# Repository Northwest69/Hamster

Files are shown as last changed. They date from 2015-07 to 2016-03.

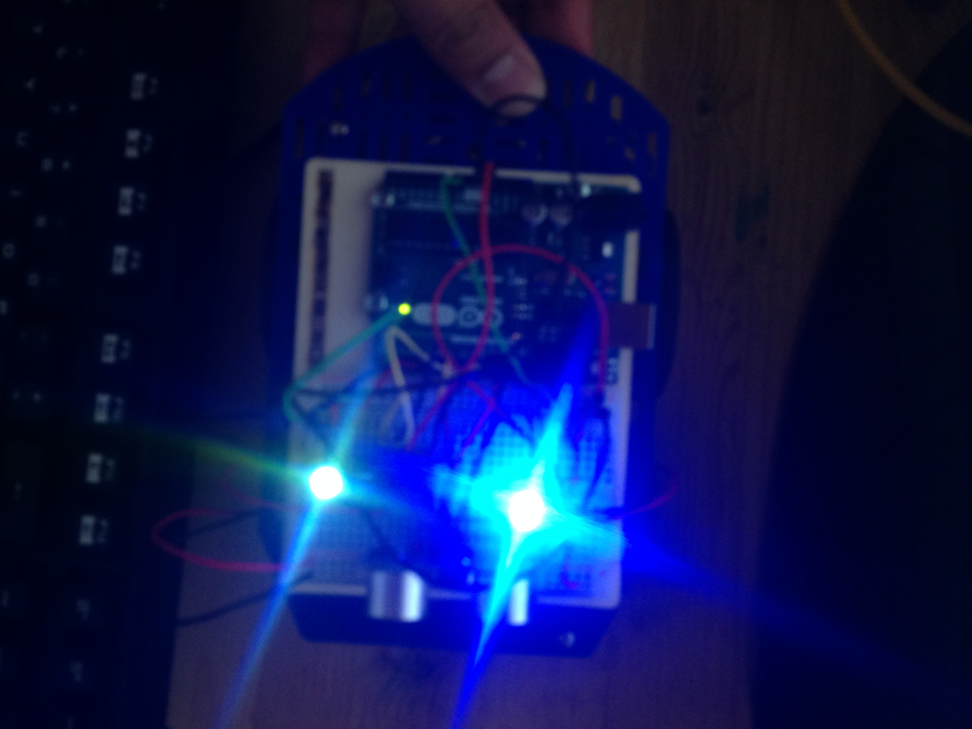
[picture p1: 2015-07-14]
Pictures/Hamster 0.2.0-1.JPG

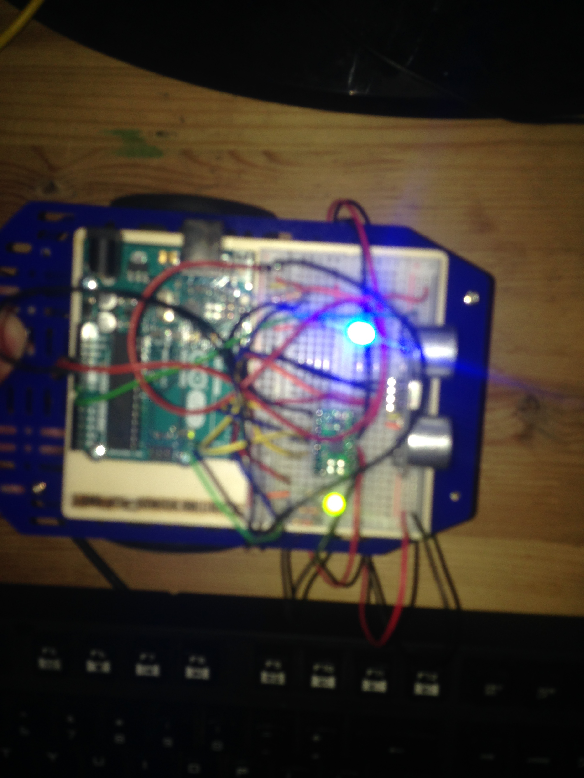
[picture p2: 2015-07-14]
Pictures/Hamster 0.2.0-2.JPG

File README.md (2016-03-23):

Hamster
=======
Firmware: 1.3.123 
Created by Peter Chau
Start Date: June 5, 2015

Hamster checks if ultraSensor sees anything in front of it. If it does, it chooses an random action based on a set of probabilities. Otherwise, Hamster drives forward. 

When Hamster is in 'Learning Mode', it evaluates it's actions and modifies the probability set until it's tried a set amount of times. The blue light is on when it's in 'Learning Mode'!

When Hamster is in 'Roam Mode', it uses the probability set to avoid objects!

When Hamster is in 'Standby Mode', it does nothing until it sees something. When it does see something, it enters 'Roam Mode'

Data is sent to Windows or Linux machine via bluetooth serial terminal.

Hardware: Arduino Uno, TI DRV8833 Dual H-Bridge Motor Driver, HC-SR04 Ultra01 + Ultrasonic Range Finder, Blue tooth Shield HC-06, HMC5883L triple axis compass
   
Log:
----
###8/14/2015 1.6.0 / 1.0.0
	Added more decimals to display probabilities
	Added new color palette

###8/13/2015 1.5.0 / 0.7.0
	Update reset command from processing to Arduino
		All fields always match Arduino
	Changed Textfield labels
	Arduino can now reset to initial probabilities, have probabilities set from processing
	Arduino can now send probabilities to processing
	Add probability stream to computer display  
	Read/Write probabilities to text file

###8/12/2015 1.4.0 / 0.5.0
	Started Implementing ControlP5 for GUI
	Processing can now set duty cycle, rotate degree, max learning attempts, and reset learning attempts
		Added submit button and key (enter)
	Learning attempts field added and Auto update display of learning attempts on processing

###8/11/2015 1.3.123 / 0.2.123
	Arduino can handle set_speed, Max learning attempts, reset learning attempts, and rotate degrees
	Processing keyPressed check added. Now processing stops serial writing when key released. 
		Hamster reenters normal operations when no signal received.

###8/10/2015 1.2.0
	Now using SerialCommand Library for string and argument based serial communication
		"D 0\r" = Drive forwards
	Fixed Standby and Roam modes

###8/9/2015 1.1.1
	Created Processing software for Hamster
	Allow Arduino to Receive Commands via bluetooth
		Can control driving instructions for drive train
			via on screen buttons
			via keys (up down left right control (stop))
	Configured Bluetooth to communicate at 38400 BAUD
		Optimized timing  to 1 loop per 50ms

###8/9/2015 1.0.1
	Memory optimizations
		Use Flash memory for strings
			Read from strings from memory for better performance (save the string only 1 time);
		Reduced code appearances for printing current probabilities more than once
		Use bytes, and boolean data types when possible

###8/8/2015 1.0.0
   Add mode switch (Learning, Standby, Roam)
   		Implemented all 3 modes
   		
###8/6/2015
	Created a prototype shield
	Power LED
	On/Off Switch

###8/4/2015 0.3.4
   Cleaned up and optimized code

###7/30/2015 0.3.3
   Implemented rotate to a degree compass navigation
      Hard-coded degrees to drive train
	  It rotates a fixed amount then stops when it's clear
   Stop motors when we see something	

###7/29/2015 0.3.2
   Enable triple axis compass
   Implemented compass navigation to drive straight
	   Added buffer so no adjustment occurs when heading difference is less than 1 degree 

###7/27/2015
   Added a probability floor

###7/22/2015
   Changed name of bluetooth module to: Hamster
   Changed Password to: Swag
   Developed Bluetooth Config Sketch

###7/21/2015
   Add Bluetooth functionality via HC-06 Bluetooth Shield
	  Sends data to computer
	  Formatted Serial data
   Changed Colors for better aesthetic
   Implement software serial for bluetooth

###7/15/2015
   Added Debounce 2 library to add functionality to debounce buttons. Perhaps this can be used to buffer actions
   Test Hamster at learningAttempts = 100, increased to 500. This works very well.
   Add exit AAN if a probability threshold is reached

###7/13/2015
   The issue was the USB cable. It is now fixed!
   Changed neural network adjustments to small decreases and increases (from 100% to 1%, and 33% to 0.33%)
   Add max training attempts (50)
     Add exit if n training attempts reached
   Add EEPROM library
     Update probabilities to EEPROM
     Nevermind... blew max writes on mem 0 already. Fuck that. Will wait for bluetooth communications
   Now using 5 different actions (stop, forwards, backwards, rotate right, rotate left)
   Add active Feedforward Back Propagation Neural Network
     Add "training mode"
   Add LED to indication which mode Hamster is in

###7/12/2015
   Added a Feedforward Neural Network for obstacle avoidance
   USB drive on computer mangled again.... Have thought out robot more. Very happy with current results.

###7/10/2015
   Ultrasonic range finder working well, however there is lag between when it detects an object and when it takes action.
     Calibrated Sensor
   Poor wheel alignment
   Implemented a status LED

###7/9/2015
   Create DC Motor drive function. void driveTrain(int instruction, int dutyCycle, int period)
   Implemented driveTrain()
   Created better serial messages
   Reworked ultrasonic range finder pinging as a state function
   ultrasonic range find needs to be calibrated. wtf. it's slow.
   ok now the robot works but is really dumb lol. it runs into stuff... lag time... momentum... go and :speed up ping

###7/8/2015
   Arduino Uno now functioning - Window's driver needed to be installed. Gave it a fresh battery charge as well.
   Updated Breadboard and schematic - was missing Uno VIN.

###7/7/2015
   Created Breadboard Diagram
   Created Schematic

###7/6/2015
   Installed DVR8833 library
   Mapped dutyCycle to motorSpeed
   I seem to have fired my Arduino UNO. Computer won't recognize it however when plugged into the wall via USB, the board works fine.

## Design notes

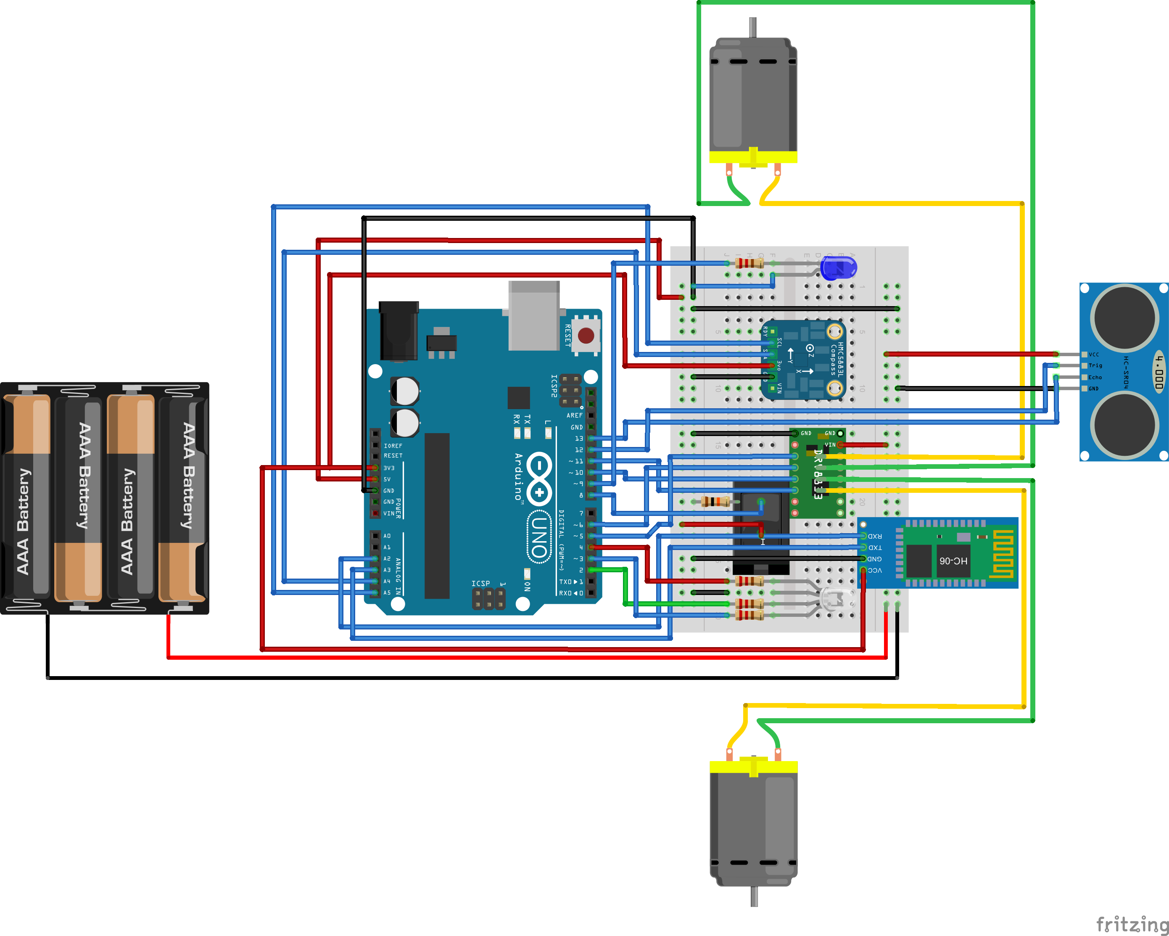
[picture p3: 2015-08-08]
Schematic/Bread Board - Hamster.png

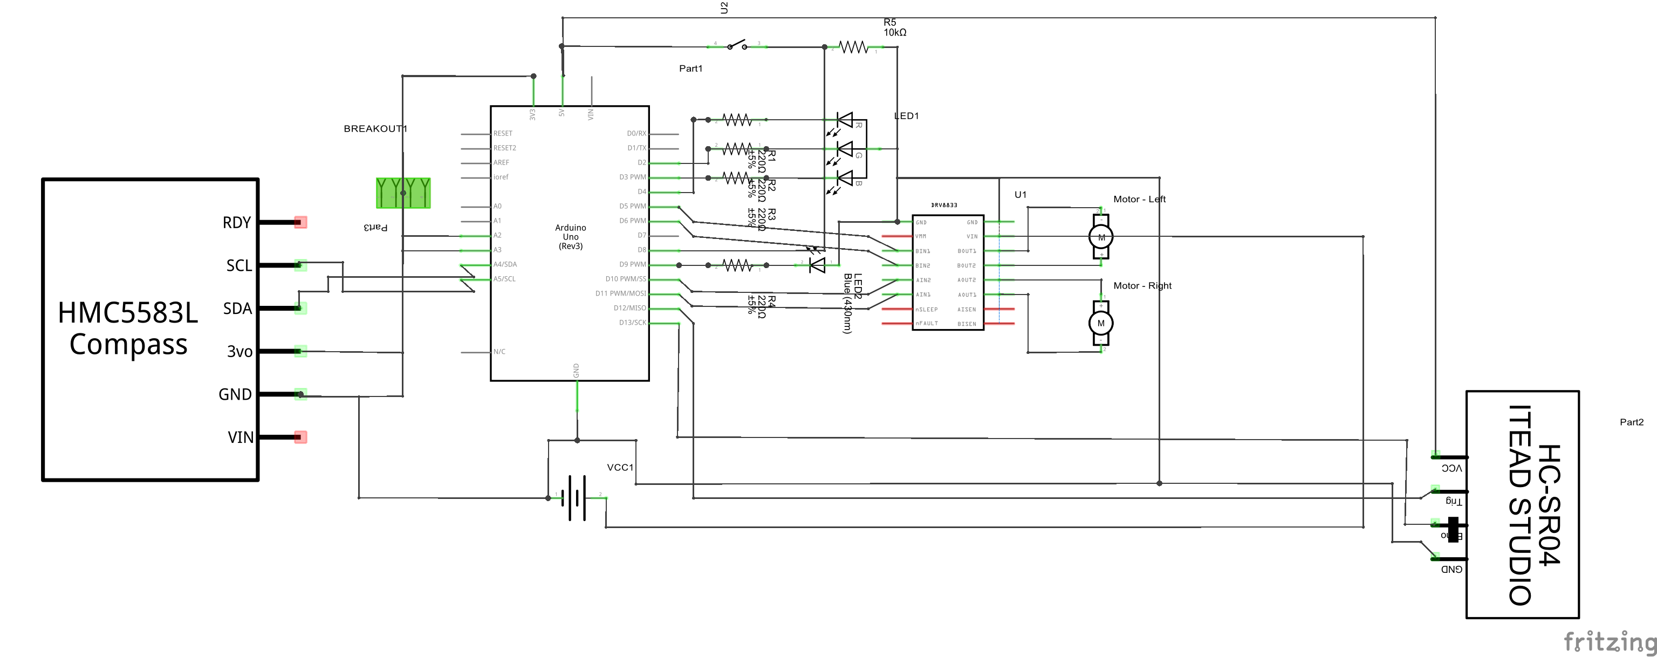
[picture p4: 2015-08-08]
Schematic/Schematic - Hamster.png

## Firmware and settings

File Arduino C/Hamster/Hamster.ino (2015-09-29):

/* Hamster
   Firmware: 1.6.0
   Created by Peter Chau
   Start Date: June 5, 2015
   Hardware: Arduino Uno, TI DRV8833 Dual H-Bridge Motor Driver, HC-SR04 Ultra01 + Ultrasonic Range Finder, Bluetooth Shield HC-06, and HMC5883L Triple axis compass
*/

#include <SoftwareSerial.h> // Include Software Serial to allow programming and bluetooth at the same time
#include <NewPing.h> // Include NewPing to handle ultraSensor data
#include <DRV8833.h> // Include DRV8833 Dual Motor Driver Carrier - Pololu  
#include <Wire.h>
#include <Adafruit_Sensor.h>
#include <Adafruit_HMC5883_U.h>
#include <math.h>
#include <SerialCommand.h> // Include to parse serial in strings

/* Bluetooth Communications constants */
const byte rxPin = A2;
const byte txPin = A3;

/* Compass Navigations variables */
float currentHeading;
float rotateDegree = 30;
byte val; // For receiving commands from Processing

/* Status LED constants and variables */
const byte statusLEDPins[] = {4, 2, 3}; // Array for Status LED with pins for red, green, and blue
byte status;

/* Drive Train constant and variables */
const byte rightMotor1 = 11;   // PWM control Right Motor -
const byte rightMotor2 = 10;   // PWM control Right Motor +
const byte leftMotor1 = 5;  // PWM control Left Motor +
const byte leftMotor2 = 6;  // PWM control Left Motor -
const int loopSpeed = 50; // 50ms between loops
long loopTimer = 0; // will store last time loop occurred
byte driveInstruction;
byte dutyCycle = 75; // Set initial 0% duty cycle PWM

/* Learning and Roam Mode constants and variables */
const byte modeSwitch = 8; // Momentary switch for putting Hamster in learn mode
const byte modeLED = 9; // LED to indicate what mode we are in
const byte roamPin = 7; // Momentary switch for putting Hamster in learn mode
boolean modeRoam = LOW; // Set inital state to drive mode (learn mode off)
boolean modeState = LOW; // Set inital state to drive mode (learn mode off)

/* Neural Network constants and variables */
const float probabilityThreshold = 0.75; // Set max probability threshold to 75%
const float probabilityFloor = 0.01; // Set probability error to 1%
boolean probabilityCheck = false; // Counter for checking if probabilities high threshold
int maxAttempts = 500; // Set max attempts to learn
int learningAttempts = 0; // Set initial attempts to learn
float probability[] = {0.16667, 0.16667, 0.16667, 0.16667, 0.16667, 0.16667}; // Set equal initial probabilities
float probabilityRemainder; // To hold remaining probability when floor has been reached, then split up amoung other probabilities

/* Ultrasonic Rangefinder constants and variables */
const byte ultraSensorTriggerPin = 12;  // Arduino pin tied to trigger pin on the ultrasonic sensor.
const byte ultraSensorEchoPin = 13;  // Arduino pin tied to echo pin on the ultrasonic sensor.
const int maxDistance = 100;
const int safeZone = 40; // 40cm between Hamster and any object
int ultraSensorCM[1]; // will stored distance from object in cm
unsigned int ultraSensorRaw; // will store raw ultrasensor range finder distance

DRV8833 driver = DRV8833(); // Create an instance of the DRV8833:
NewPing ultraSensor(ultraSensorTriggerPin, ultraSensorEchoPin, maxDistance); // NewPing setup of pins and maximum distance.
SoftwareSerial bluetooth = SoftwareSerial(rxPin, txPin); // RX, TX for bluetooth
SerialCommand SCmd(bluetooth);   // The demo SerialCommand object, using the SoftwareSerial Constructor

Adafruit_HMC5883_Unified compass = Adafruit_HMC5883_Unified(12345); // Create compass object

void setup() {
  /* Initalize pins for bluetooth*/
  pinMode(rxPin, INPUT);
  pinMode(txPin, OUTPUT);
  bluetooth.begin(38400);

  /* Setup callbacks for SerialCommand commands */
  SCmd.addCommand("D", driveCommand); // Drive command
  SCmd.addCommand("S", setDutyCycle); // Speed command
  SCmd.addCommand("L", learningMax); // Max Learning Attempts command
  SCmd.addCommand("R", reset); // Reset Learning Attempts command
  SCmd.addCommand("T", setRotateDegree); //Set Rotate Degree command
  SCmd.addCommand("P", setProbability); //Set Rotate Degree command
  
  /* Initialize mode button and LED */
  pinMode(modeSwitch, INPUT);
  pinMode(modeLED, OUTPUT);

  /* Initialise the sensor */
  if (!compass.begin()) {
    while (1);
  }

  /* Attach the motors to the input pins: */
  driver.attachMotorA(rightMotor1, rightMotor2);
  driver.attachMotorB(leftMotor1, leftMotor2);

  /* Attach status LED to output pins */
  for (byte x = 0; x < 3; x++) {
    pinMode(statusLEDPins[x], OUTPUT);
  }

  bluetooth.println("\n\rH A M S T E R v1.3.0 <3\n");
  statusLed(0); // Set status LED to Ready (green)
}

void loop() {
  if (bluetooth.available()>0){
    SCmd.readSerial();     // Process serial commands
  }
  
  /* Measure the time since last loop */
  unsigned long currentLoopMillis = millis(); // record current time
  if (currentLoopMillis - loopTimer > loopSpeed) { // save the last time you looped
    loopTimer += loopSpeed; // update time since last ping

    statusLed(4); // Ping status (light blue)
    ultraSensorRaw = ultraSensor.ping(); // Send ping, get ping time in microseconds (uS).

    /* Hamster checks if ultraSensor sees anything 40 cm in front of it */
    ultraSensorCM[0] = ultraSensorRaw / US_ROUNDTRIP_CM; // Convert ping time to distance in cm (0 = outside set distance range)
    if (ultraSensorCM[0] > 0 && ultraSensorCM[0] <= safeZone) {
      driveTrain(6, dutyCycle, 0, currentHeading); // Stop motors when something is detected within safe zone
      statusLed(1); // Object Avoidance status (Red)

      /* Use probability to pick an object avoidance action and perform it */
      driveInstruction = weightedRandom(probability);
      driveTrain(driveInstruction, dutyCycle, rotateDegree, currentHeading);

      modeState = digitalRead(modeSwitch); // What mode are we in? Learning or Drive mode.

      /* Use Forewardfeed Back Proprogation Neural Network if Hamster is in Learning Mode and has tried to learn less than max learning attempts */
      if (modeState == HIGH && (learningAttempts < maxAttempts)) {

        /* Check if any probability has reached the probability threshold */
        for (byte x = 0; x < 6; x++) {
          if (probability[x] >= probabilityThreshold) {
            probabilityCheck = true;
            digitalWrite(modeLED, LOW); // Turn off Learning Mode LED
          }
        }

        if (probabilityCheck == false) {
          digitalWrite(modeLED, HIGH); // Turn on Learning Mode LED

          ultraSensorRaw = ultraSensor.ping(); // Ping and save it to ultraSensorCM[1]
          ultraSensorCM[1] = ultraSensorRaw / US_ROUNDTRIP_CM;

          if (ultraSensorCM[1] <= ultraSensorCM[0]) { // Check if action was successful based on change in distance
            for (byte x = 0; x < 6; x++) { // Decrease drive instruction's probability
              if (x == driveInstruction) {
                probability[x] = probability[x] - 0.001000;
              } else {
                probability[x] = probability[x] + 0.000167;
              }
              status = 5; // Action Failed status (light red)
            }
          }
          else {
            for (byte x = 0; x < 6; x++) { // Increase drive instruction's probability
              if (x == driveInstruction) {
                probability[x] = probability[x] + 0.001000;
              } else {
                probability[x] = probability[x] - 0.000167;
              }
              status = 2; // Action Success status (Blue)
            }
          }

          /* Check if any probabilityFloor has been reached*/
          for (byte x = 0; x < 6; x++) {
            if (probability[x] <= probabilityFloor) {
              /* Split remaining probability up between other probabilities */
              probabilityRemainder = probability[x];
              probability[x] = 0;
              for (byte x = 0; x < 6; x++) {
                if (probability != 0) {
                  probability[x] += probabilityRemainder / 6;
                }
              }
            }
          }

          learningAttempts++; // Increase learning tracker
          
          bluetooth.print("C "); bluetooth.println(learningAttempts);
          bluetooth.print("P "); bluetooth.print(String(probability[0], 6));
          bluetooth.print(" "); bluetooth.print(String(probability[1], 6));
          bluetooth.print(" "); bluetooth.print(String(probability[2], 6));
          bluetooth.print(" "); bluetooth.print(String(probability[3], 6));
          bluetooth.print(" "); bluetooth.print(String(probability[4], 6));
          bluetooth.print(" "); bluetooth.println(String(probability[5], 6));
        }
      } else if (modeState == LOW || (learningAttempts >= maxAttempts)) {
        digitalWrite(modeLED, LOW); // Turn off Learning Mode LED
      }

    } else {
      // Go forwards
      driveInstruction = 0; // Drive Forwards
      status = 3; // Wander status (Purple)

      /* Check if we are driving straight */
      if (driveInstruction == 0) { //
        float targetHeading = currentHeading; // Set target heading
        currentHeading = readCompass(); // Find current heading
        float difference = targetHeading - currentHeading;
        if ( difference > -1 && difference < 1) { // Add buffer so this doesn't run all the time
          driveInstruction = adjustHeading(difference); // Determine rotation direction: CCW or CW
        }
      }

      /* Check if we are in Standby Mode */
      modeRoam = digitalRead(roamPin);
      if (modeRoam == HIGH || modeState == HIGH) {
        currentHeading = readCompass(); // Get current heading
        driveTrain(driveInstruction, dutyCycle, rotateDegree, currentHeading);
      }
    }
    statusLed(status);
  }

} // loop() end

void driveCommand() {
  int aNumber;
  char *arg;

  arg = SCmd.next();
  if (arg != NULL)  {
    aNumber = atoi(arg);  // Converts a char string to an integer
    if (aNumber >= 0 && aNumber < 7) {
      currentHeading = readCompass(); // Get current heading
      driveTrain(aNumber, dutyCycle, rotateDegree, currentHeading);
    }
  }
}

void setDutyCycle() {
  int aNumber;
  char *arg;

  arg = SCmd.next();
  if (arg != NULL)  {
    aNumber = atoi(arg);  // Converts a char string to an integer
    if (aNumber >= 0 && aNumber <= 100) {
      dutyCycle = aNumber; // Set duty cycle PWM
    }
  }
}

void setRotateDegree() {
  int aNumber;
  char *arg;

  arg = SCmd.next();
  if (arg != NULL)  {
    aNumber = atoi(arg);  // Converts a char string to an integer
    if (aNumber >= 1 && aNumber <= 360) {
      rotateDegree = aNumber; // Set max attempts to learn
    }
  }
}

void learningMax() {
  int aNumber;
  char *arg;

  arg = SCmd.next();
  if (arg != NULL)  {
    aNumber = atoi(arg);  // Converts a char string to an integer
    if (aNumber >= 0 && aNumber <= 10000) {
      maxAttempts = aNumber; // Set max attempts to learn
    }
  }
}

void setProbability() {
  int aNumber;
  char *arg;

  for(int x = 0; x < 6; x++){
  arg = SCmd.next();
  if (arg != NULL)  {
    aNumber = atoi(arg);  // Converts a char string to an integer
    if (aNumber >= 0 && aNumber <= 1) {
      probability[x] = aNumber; // Set max attempts to learn
    }
  }
}
}

void reset() {
  // Reset to initial values
  learningAttempts = 0;
  maxAttempts = 500;
  dutyCycle = 75;
  rotateDegree = 30;
  for(int x = 0; x < 6; x++){
      probability[x] = 0.1666667; // Set max attempts to learn
    }
  }

/* Drive Train for 2 motors on opposite sides */
void driveTrain(byte instruction, byte dutyCycle, float rotateDegree, float currentHeading) {
  int motorSpeed = map(dutyCycle, 0, 100, 0, 255); // Map motorSpeed (255 - 0) to dutyCycle (0 - 100)
  float targetHeading;
  float difference;

  switch (instruction) {
    case 0: // Forward
      driver.motorAForward(motorSpeed);
      driver.motorBForward(motorSpeed);
      break;
    case 1: // Backwards
      driver.motorAReverse(motorSpeed);
      driver.motorBReverse(motorSpeed);
      break;
    case 2: // Rotate CW
      if ((currentHeading + rotateDegree) >= 360) {
        targetHeading = currentHeading + rotateDegree - 360; // Set target heading
      } else {
        targetHeading = currentHeading + rotateDegree; // Set target heading
      }
      difference = targetHeading - currentHeading;
      while ((difference < -15) || (difference > 15)) { // Add buffer so this doesn't run all the time
        driver.motorAReverse(motorSpeed);
        driver.motorBForward(motorSpeed);
        currentHeading = readCompass(); // Find current heading
        difference = targetHeading - currentHeading;
        if ((difference < 10) && (difference > -10)) {
          break;
        }
      }
      break;
    case 3: // Rotate CCW
      if ((currentHeading - rotateDegree) < 0) {
        targetHeading = currentHeading - rotateDegree + 360; // Set target heading
      } else {
        targetHeading = currentHeading - rotateDegree; // Set target heading
      }
      difference = targetHeading - currentHeading;
      while ( (difference < -15) || (difference > 15)) { // Add buffer so this doesn't run all the time
        driver.motorAForward(motorSpeed);
        driver.motorBReverse(motorSpeed);

        currentHeading = readCompass(); // Find current heading
        difference = targetHeading - currentHeading;
        if ((difference < 10) && (difference > -10)) {
          break;
        }
      }
      break;
    case 4: // Rotate right
      driver.motorAReverse(motorSpeed);
      driver.motorBForward(motorSpeed);
      break;
    case 5: // Rotate left
      driver.motorAForward(motorSpeed);
      driver.motorBReverse(motorSpeed);
      break;
    case 6: // Stop
      driver.motorAStop();
      driver.motorBStop();
      break;
  }
  return;
}

/* Controls status LED */
void statusLed(byte status) {
  switch (status) {
    case 0: // set to LED green to indicate status
      digitalWrite(statusLEDPins[1], LOW);
      digitalWrite(statusLEDPins[0], LOW);
      if (digitalRead(statusLEDPins[2]) != HIGH) {
        digitalWrite(statusLEDPins[2], HIGH);
      }
      break;
    case 1: // set to LED red to indicate status
      digitalWrite(statusLEDPins[2], LOW);
      digitalWrite(statusLEDPins[1], LOW);
      if (digitalRead(statusLEDPins[0]) != HIGH) {
        digitalWrite(statusLEDPins[0], HIGH);
      }
      break;
    case 2: // set to LED blue to indicate status
      digitalWrite(statusLEDPins[0], LOW);
      digitalWrite(statusLEDPins[2], LOW);
      if (digitalRead(statusLEDPins[1]) != HIGH) {
        digitalWrite(statusLEDPins[1], HIGH);
      }
      break;
    case 3: // set to LED purple to indicate status
      digitalWrite(statusLEDPins[1], LOW);
      if (digitalRead(statusLEDPins[2]) != HIGH) {
        digitalWrite(statusLEDPins[2], HIGH);
      }
      if (digitalRead(statusLEDPins[0]) != HIGH) {
        digitalWrite(statusLEDPins[0], HIGH);
      }
      break;
    case 4: // set to LED light blue to indicate status
      digitalWrite(statusLEDPins[0], LOW);
      if (digitalRead(statusLEDPins[2]) != HIGH) {
        digitalWrite(statusLEDPins[2], HIGH);
      }
      if (digitalRead(statusLEDPins[1]) != HIGH) {
        digitalWrite(statusLEDPins[1], HIGH);
      }
      break;
    case 5: // set to LED light red to indicate status
      digitalWrite(statusLEDPins[2], LOW);
      if (digitalRead(statusLEDPins[0]) != HIGH) {
        digitalWrite(statusLEDPins[0], HIGH);
      }
      if (digitalRead(statusLEDPins[1]) != HIGH) {
        digitalWrite(statusLEDPins[1], HIGH);
      }
      break;
  }
}

/* Weighted Random Choice  */
byte weightedRandom(float* weights) {
  float seed = random(3.14); // seed the countdown with pi (yum)
  float choice = seed * 1; // reduce the seed and save into countdown
  for (byte x = 0; x < 6; x++) { // minus each probability from choice
    choice -= weights[x];
    if (choice < 0) {
      return x; // return weight index
    }
  }
}

/* Read Triple axis compass */
float readCompass() {
  /* Get a new sensor event */
  sensors_event_t event;
  compass.getEvent(&event);

  // Calculate heading when the magnetometer is level, then correct for signs of axis.
  float heading = atan2(event.magnetic.y, event.magnetic.x);
  float declinationAngle = 0.22;
  heading += declinationAngle;

  // Correct for when signs are reversed.
  if (heading < 0)
    heading += 2 * PI;
  // Check for wrap due to addition of declination.
  if (heading > 2 * PI)
    heading -= 2 * PI;

  // Convert radians to degrees for readability.
  float headingDegrees = heading * 180 / M_PI;

  return headingDegrees;
}

/* Determine which direction we need to rotate: CCW or CW */
byte adjustHeading(float difference) {
  if (difference < -270) {
    return 4;
  } else if (difference > -270 && difference < 0) {
    return 5;
  } else if (difference < 270 && difference > 0) {
    return 4;
  } else if (difference > 270 && difference > 0) {
    return 5;
  }
}

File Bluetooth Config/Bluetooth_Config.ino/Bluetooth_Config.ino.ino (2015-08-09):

#include <SoftwareSerial.h>

SoftwareSerial mySerial(A2, A3); // RX, TX

String command = ""; // Stores response of the HC-06 Bluetooth device

void setup() {
// Open serial communications:
Serial.begin(9600);
Serial.println("Type AT commands!");

// The HC-06 defaults to 9600 according to the datasheet.
mySerial.begin(38400);
}

void loop() {
// Read device output if available.
if (mySerial.available()) {
while(mySerial.available()) { // While there is more to be read, keep reading.
command += (char)mySerial.read();
}

Serial.println(command);
command = ""; // No repeats
}

// Read user input if available.
if (Serial.available()){
delay(10); // The delay is necessary to get this working!
mySerial.write(Serial.read());
}
}

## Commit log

2015-07-14 SVN Implemented
    [Schematic - Hamster 0.1.2.fzz]
2015-07-16 Cleaned up code, updated README, and adjusted status colors
    [Schematic - Hamster 0.12.fzz]
2015-07-16 Implemented a probability threshold with a margin of error to determine if Hamster should keep learning
    [Hamster.ino]
2015-08-08 Implemented 3 modes, mode switch, and power switch
    [Schematic - Hamster 0.1.2.fzz]
2015-08-08 Updated directory and fritzing, breadboard, schmatic
    [Hamster.fzz, Schematic - Hamster 0.1.2.fzz, Schematic - Hamster 0.12.fzz]
2015-08-10 See loop timer to control jitter
    [Hamster.ino, Hamster.pde]
2015-08-13 Added new directional buttons
2015-08-13 Control Learning Mode: Max attempts and reset current attempts from processing
    [Hamster.ino, Hamster.pde]
2015-08-13 Working to implement autoupdate of current attempts
2015-08-14 Fully implemented reset button
2015-09-29 Fixed Probability bug - buffer overflow from too many decimals
    [Hamster.ino, Hamster.pde]
